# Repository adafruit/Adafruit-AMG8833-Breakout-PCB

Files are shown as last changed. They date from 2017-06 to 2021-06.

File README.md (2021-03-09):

## Adafruit AMG8833 Breakout PCB

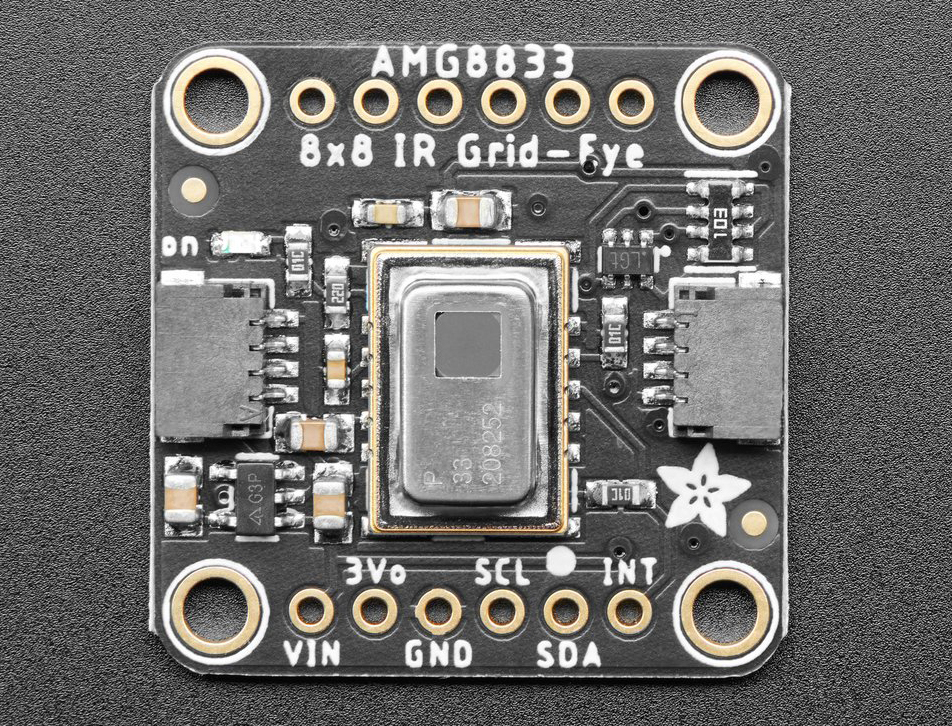
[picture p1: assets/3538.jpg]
<a href="http://www.adafruit.com/products/3538"><br/>
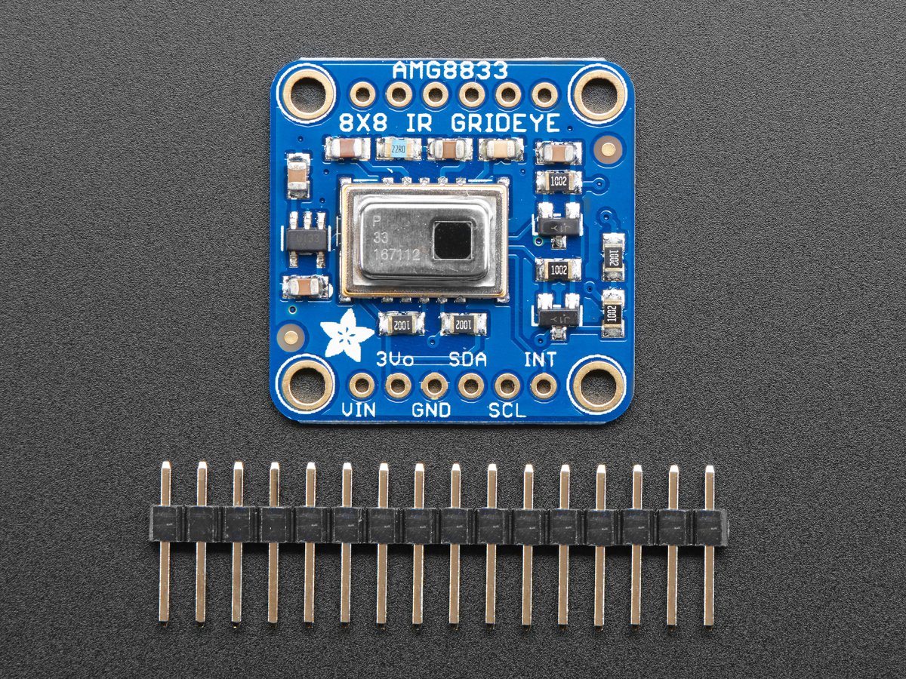
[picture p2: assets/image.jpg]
<a href="http://www.adafruit.com/products/3538"><br/>
Click here to purchase one from the Adafruit shop</a>

PCB files for the Adafruit AMG8833 8x8 IR sensor breakout board. Format is EagleCAD schematic and board layout

For more details, check out the product page at
* https://www.adafruit.com/products/3538

### Description

Add heat-vision to your project and with an Adafruit AMG8833 Grid-EYE Breakout! This sensor from Panasonic is an 8x8 array of IR thermal sensors. When connected to your microcontroller (or raspberry Pi) it will return an array of 64 individual infrared temperature readings over I2C. It's like those fancy thermal cameras, but compact and simple enough for easy integration.

This part will measure temperatures ranging from 0°C to 80°C (32°F to 176°F) with an accuracy of +- 2.5°C (4.5°F). It can detect a human from a distance of up to 7 meters (23) feet. With a maximum frame rate of 10Hz, It's perfect for creating your own human detector or mini thermal camera. We have code for using this breakout on an Arduino or compatible (the sensor communicates over I2C) or on a Raspberry Pi with Python. On the Pi, with a bit of image processing help from the SciPy python library we were able to interpolate the 8x8 grid and get some pretty nice results!

The AMG8833 is the next generation of 8x8 thermal IR sensors from Panasonic, and offers higher performance than it's predecessor the AMG8831. The sensor only supports I2C, and has a configurable interrupt pin that can fire when any individual pixel goes above or below a threshold that you set.

To make it easy to use, we pick & placed it on a breakout board with a 3.3V regulator and level shifting. So you can use it with any 3V or 5V microcontroller or computer.

### License

Adafruit invests time and resources providing this open source design, please support Adafruit and open-source hardware by purchasing products from [Adafruit](https://www.adafruit.com)!

Designed by Limor Fried/Ladyada for Adafruit Industries.

Creative Commons Attribution/Share-Alike, all text above must be included in any redistribution. See license.txt for additional details.

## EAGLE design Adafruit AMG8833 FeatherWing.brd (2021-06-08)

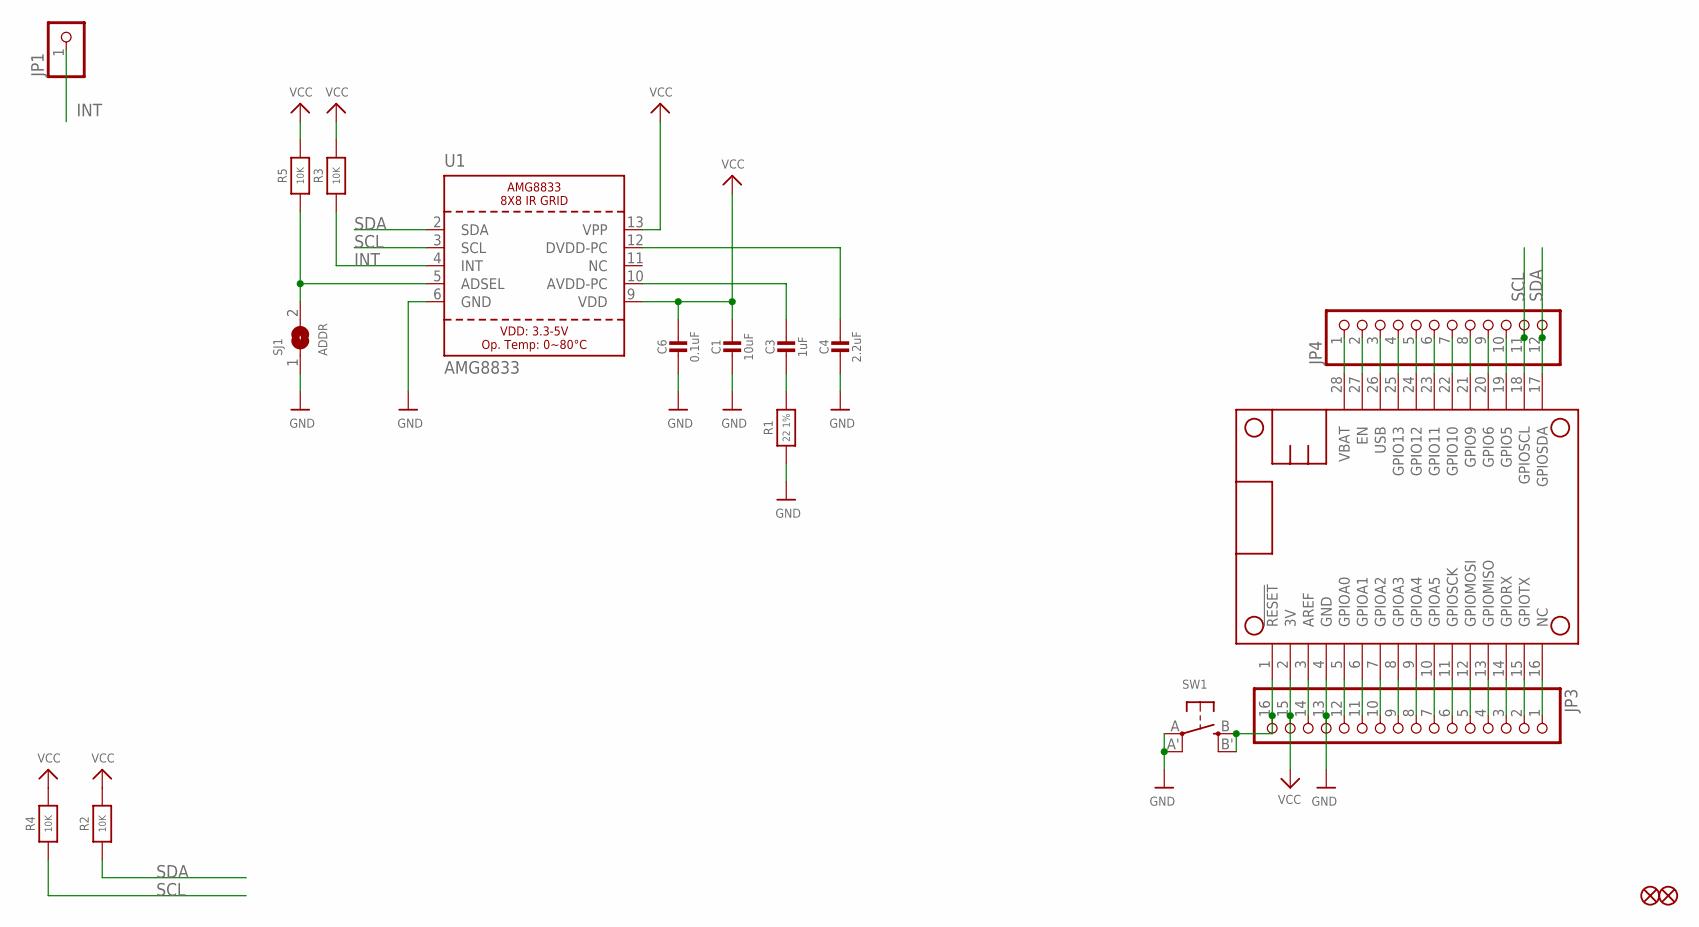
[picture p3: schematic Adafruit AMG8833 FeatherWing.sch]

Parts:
C1: 10uF; 0805-NO
C3: 1uF; 0805-NO
C4: 2.2uF; 0805-NO
C6: 0.1uF; 0805-NO
FID1, FID2: FIDUCIAL""; FIDUCIAL_1MM
JP1: HEADER-1X1ROUND; 1X01_ROUND
JP3: HEADER-1X16ROUND; 1X16_ROUND
JP4: HEADER-1X12; 1X12_ROUND
MS1: FEATHERWING
R1: 22 1%; 0805-NO
R2, R3, R4, R5: 10K; 0805-NO
SJ1: ADDR; SOLDERJUMPER_ARROW_NOPASTE
SW1: SWITCH_TACT_SMT4.6X2.8; BTN_KMR2_4.6X2.8
U1: AMG8833

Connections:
A: JP3.12, MS1.5 (GPIOA0)
AREF: JP3.14, MS1.3 (AREF)
AVDD-PC1: C3.1, U1.10 (AVDD-PC)
B: JP3.11, MS1.6 (GPIOA1)
C: JP3.10, MS1.7 (GPIOA2)
D: JP3.9, MS1.8 (GPIOA3)
DVDD-PC1: C4.1, U1.12 (DVDD-PC)
E: JP3.8, MS1.9 (GPIOA4)
EN: JP4.2, MS1.27 (EN)
F: JP3.7, MS1.10 (GPIOA5)
G: JP3.1, MS1.16 (NC)
GND: C1.2, C4.2, C6.2, JP3.13, MS1.4 (GND), R1.1, SJ1.1, SW1.A, SW1.A' (P1), U1.6 (GND)
H: JP4.10, MS1.19 (GPIO5)
I: JP4.9, MS1.20 (GPIO6)
INT: JP1.1, R3.1, U1.4 (INT)
J: JP4.8, MS1.21 (GPIO9)
K: JP4.7, MS1.22 (GPIO10)
L: JP4.6, MS1.23 (GPIO11)
M: JP4.5, MS1.24 (GPIO12)
MISO: JP3.4, MS1.13 (GPIOMISO)
MOSI: JP3.5, MS1.12 (GPIOMOSI)
N: JP4.4, MS1.25 (GPIO13)
unnamed: R5.1, SJ1.2, U1.5 (ADSEL)
unnamed: C3.2, R1.2
RESET: JP3.16, MS1.1 (!RESET), SW1.B (S), SW1.B' (S1)
RX: JP3.3, MS1.14 (GPIORX)
SCK: JP3.6, MS1.11 (GPIOSCK)
SCL: JP4.11, MS1.18 (GPIOSCL), R4.1, U1.3 (SCL)
SDA: JP4.12, MS1.17 (GPIOSDA), R2.1, U1.2 (SDA)
TX: JP3.2, MS1.15 (GPIOTX)
USB: JP4.3, MS1.26 (USB)
VBAT: JP4.1, MS1.28 (VBAT)
VCC: C1.1, C6.1, JP3.15, MS1.2 (3V), R2.2, R3.2, R4.2, R5.2, U1.9 (VDD), U1.13 (VPP)

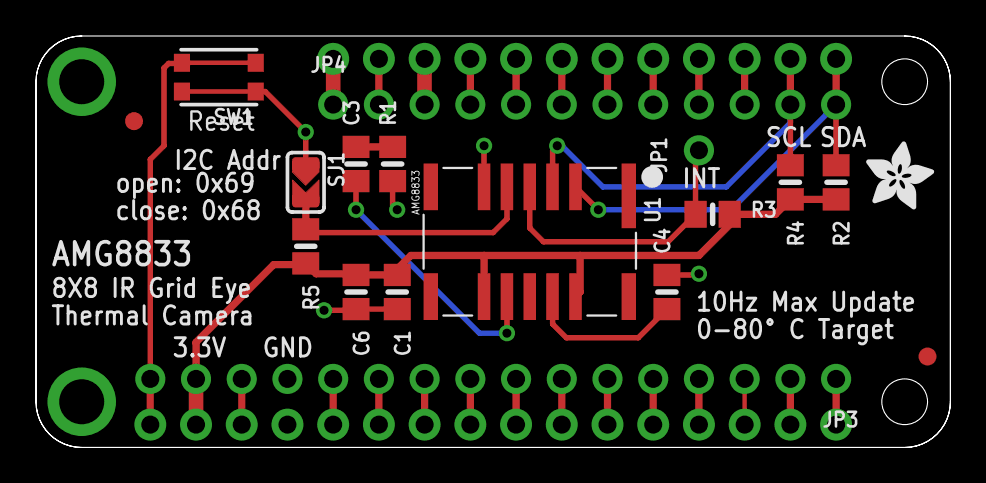
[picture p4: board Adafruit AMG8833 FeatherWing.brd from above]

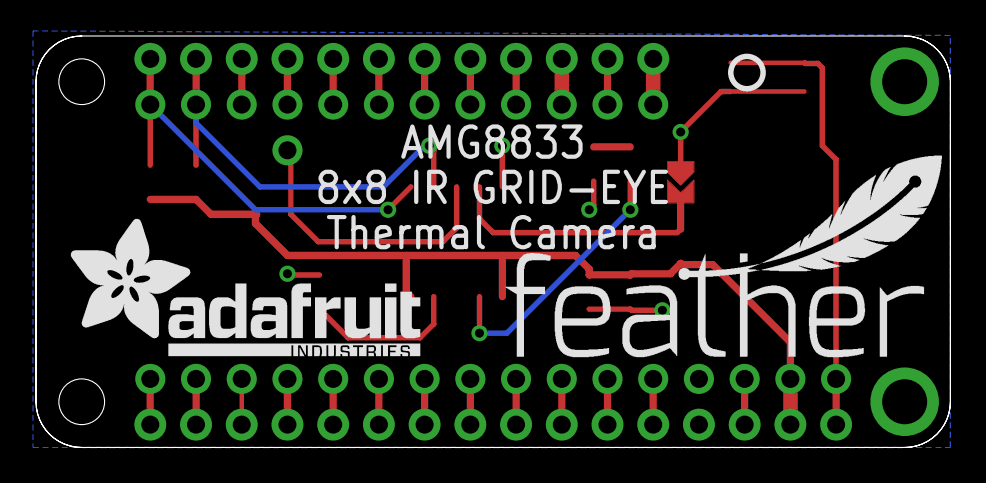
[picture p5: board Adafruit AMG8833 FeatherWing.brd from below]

Board: 2 copper layers, 50.8 x 22.9 mm, 22 parts (3 on the bottom side), 33 nets.

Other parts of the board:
U$2: ADAFRUIT_TEXT_20MM
U$14: ADAFRUIT_3.5MM
U$15: FEATHERLOGO
U$16: PCBFEAT-REV-040

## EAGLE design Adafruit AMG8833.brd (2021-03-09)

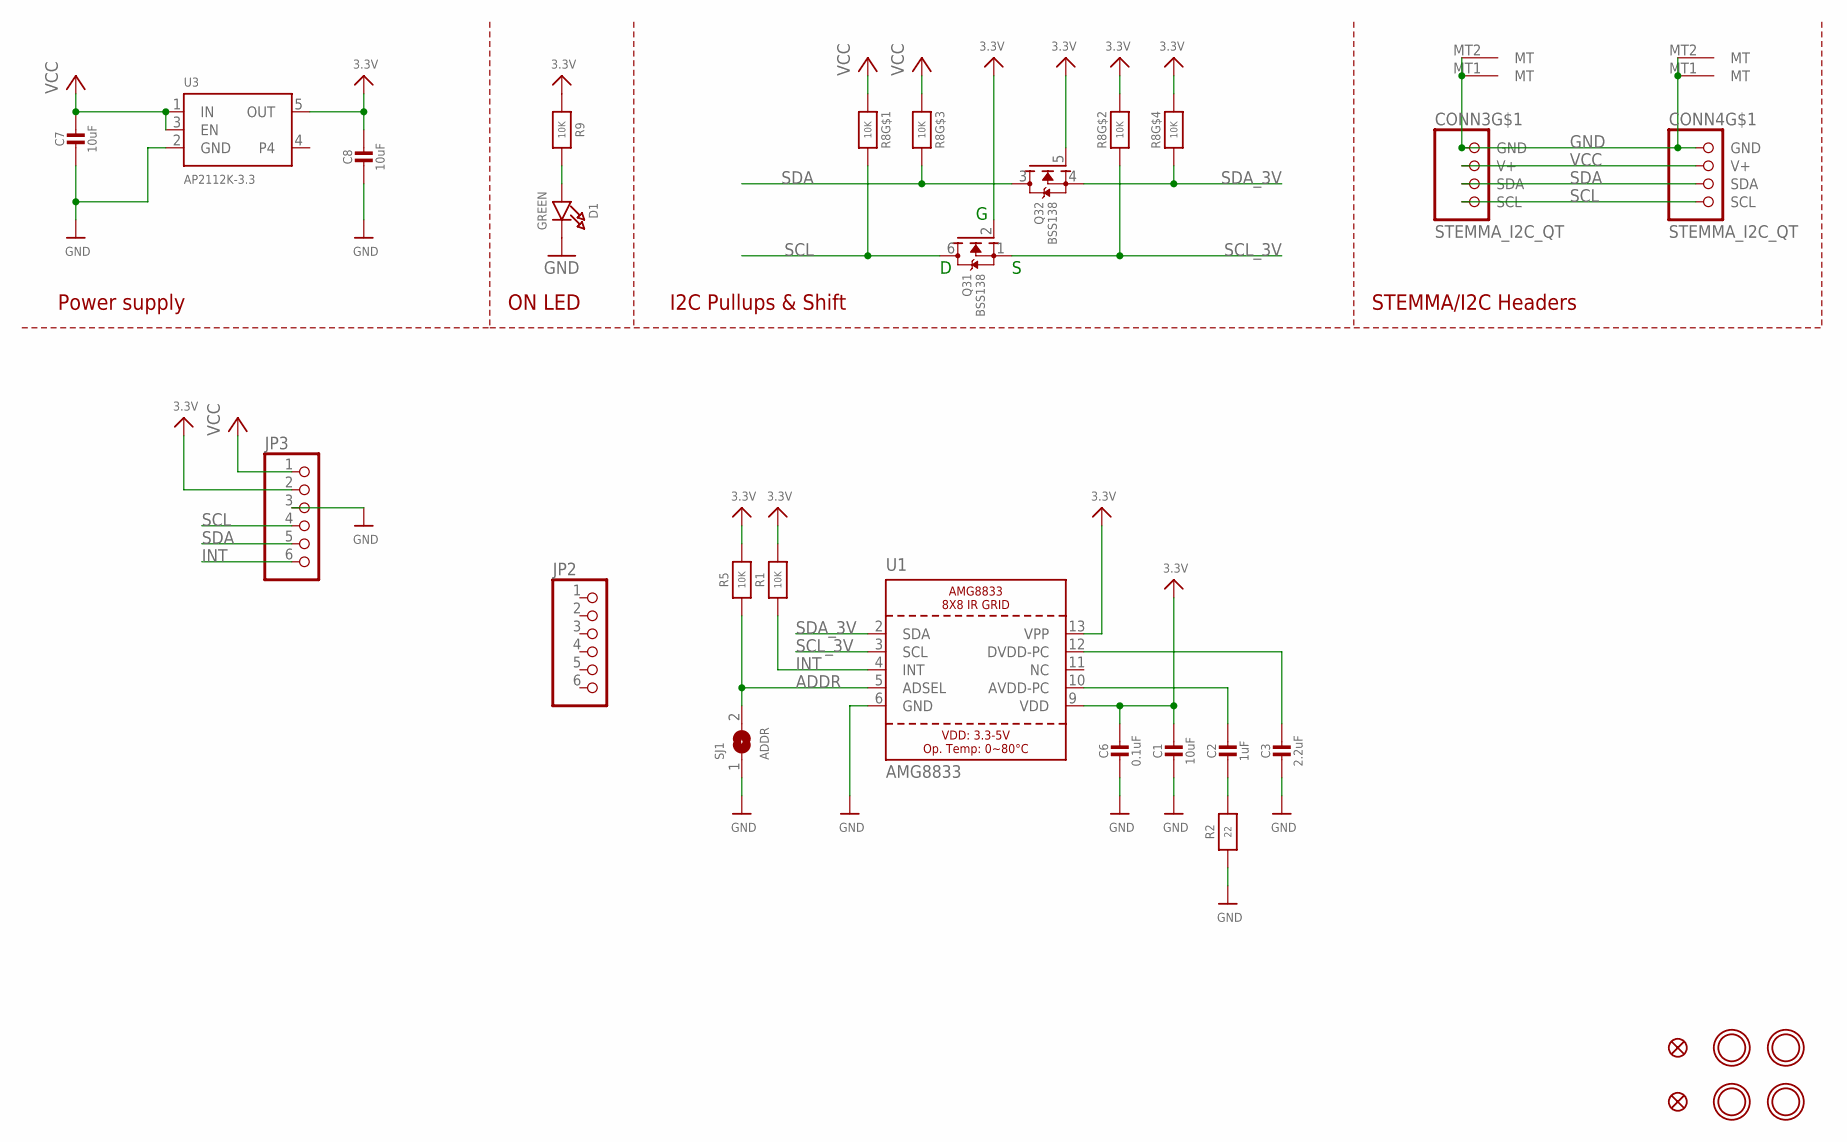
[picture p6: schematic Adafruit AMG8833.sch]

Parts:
C1, C7, C8: 10uF; 0805-NO
C2: 1uF; 0603-NO
C3: 2.2uF; 0805-NO
C6: 0.1uF; 0603-NO
CONN3, CONN4: STEMMA_I2C_QT; JST_SH4
D1: GREEN; CHIPLED_0603_NOOUTLINE
FID1, FID4: FIDUCIAL_1MM
JP2, JP3: HEADER-1X670MIL; 1X06_ROUND_70
Q3: BSS138; SOT363
R1, R5, R9: 10K; 0603-NO
R2: 22; 0603-NO
R8: 10K; RESPACK_4X0603
SJ1: ADDR; SOLDERJUMPER_ARROW_NOPASTE
U1: AMG8833
U3: AP2112K-3.3; SOT23-5
U$40, U$41, U$43, U$44: MOUNTINGHOLE2.5; MOUNTINGHOLE_2.5_PLATED

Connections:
3.3V: C1.1, C6.1, C8.1, JP3.2, Q3.2 (G), Q3.5 (G), R1.2, R5.2, R8.2 (1), R8.4 (1), R9.1, U1.9 (VDD), U1.13 (VPP), U3.5 (OUT)
ADDR: R5.1, SJ1.2, U1.5 (ADSEL)
AVDD-PC: C2.1, U1.10 (AVDD-PC)
DVDD-PC: C3.1, U1.12 (DVDD-PC)
GND: C1.2, C3.2, C6.2, C7.2, C8.2, CONN3.1 (GND), CONN3.MT1 (MT), CONN3.MT2 (MT), CONN4.1 (GND), CONN4.MT1 (MT), CONN4.MT2 (MT), D1.C, JP3.3, R2.1, SJ1.1, U1.6 (GND), U3.2 (GND)
INT: JP3.6, R1.1, U1.4 (INT)
unnamed: D1.A, R9.2
unnamed: C2.2, R2.2
SCL: CONN3.4 (SCL), CONN4.4 (SCL), JP3.4, Q3.6 (D), R8.8 (2)
SCL_3V: Q3.1 (S), R8.7 (2), U1.3 (SCL)
SDA: CONN3.3 (SDA), CONN4.3 (SDA), JP3.5, Q3.3 (D), R8.6 (2)
SDA_3V: Q3.4 (S), R8.5 (2), U1.2 (SDA)
VCC: C7.1, CONN3.2 (V+), CONN4.2 (V+), JP3.1, R8.1, R8.3 (1), U3.1 (IN), U3.3 (EN)

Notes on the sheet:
I2C Pullups & Shift
STEMMA/I2C Headers
ON LED
Power supply

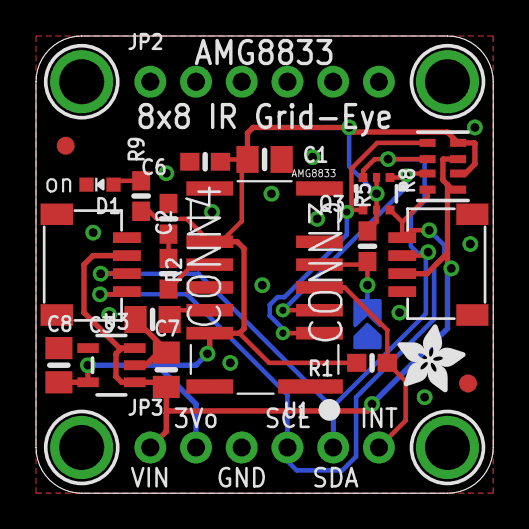
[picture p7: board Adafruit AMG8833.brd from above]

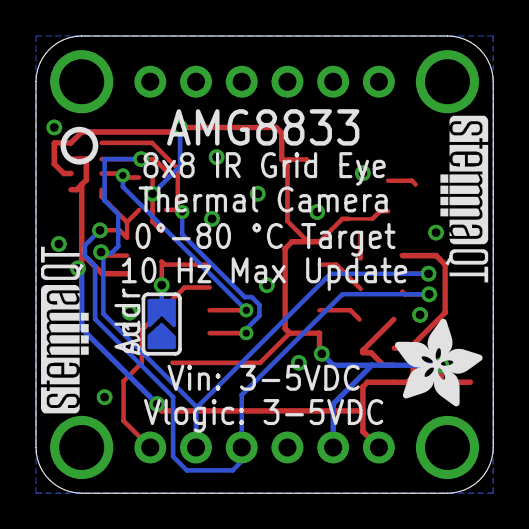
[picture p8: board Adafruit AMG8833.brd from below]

Board: 2 copper layers, 25.4 x 25.4 mm, 31 parts (5 on the bottom side), 13 nets.

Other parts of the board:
U$28: ADAFRUIT_5MM
U$46: ADAFRUIT_3.5MM
U$47: PCBFEAT-REV-040
U$48, U$49: STEMMAQT

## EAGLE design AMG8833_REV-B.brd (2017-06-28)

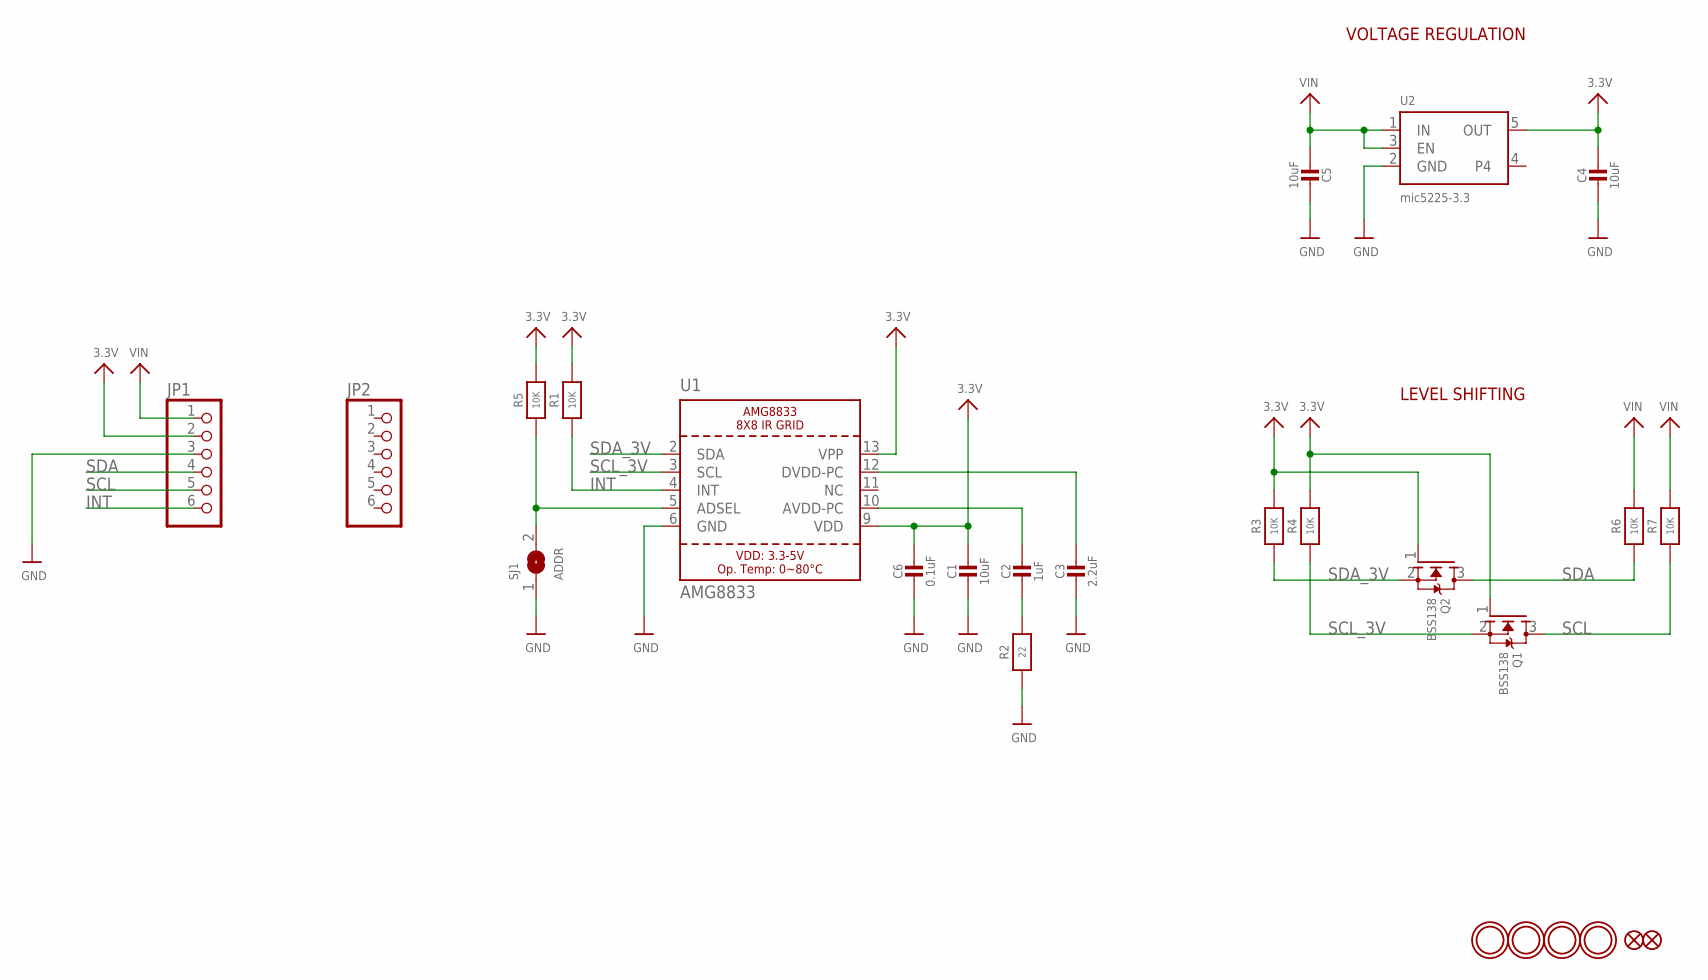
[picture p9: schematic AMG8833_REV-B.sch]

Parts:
C1, C4, C5: 10uF; 0805-NO
C2: 1uF; 0805-NO
C3: 2.2uF; 0805-NO
C6: 0.1uF; 0805-NO
FID2, FID3: FIDUCIAL_1MM
JP1, JP2: HEADER-1X670MIL; 1X06_ROUND_70
Q1, Q2: BSS138; SOT23-WIDE
R1, R3, R4, R5: 10K; 0805-NO
R2: 22; 0805-NO
R6, R7: 10K; 0805_10MGAP
SJ1: ADDR; SOLDERJUMPER_ARROW_NOPASTE
U1: AMG8833
U2: mic5225-3.3; SOT23-5
U$16, U$17, U$18, U$19: MOUNTINGHOLE2.5; MOUNTINGHOLE_2.5_PLATED

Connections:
3.3V: C1.1, C4.1, C6.1, JP1.2, Q1.1 (G), Q2.1 (G), R1.2, R3.2, R4.2, R5.2, U1.9 (VDD), U1.13 (VPP), U2.5 (OUT)
AVDD-PC: C2.1, U1.10 (AVDD-PC)
DVDD-PC: C3.1, U1.12 (DVDD-PC)
GND: C1.2, C3.2, C4.2, C5.1, C6.2, JP1.3, R2.1, SJ1.1, U1.6 (GND), U2.2 (GND)
INT: JP1.6, R1.1, U1.4 (INT)
unnamed: R5.1, SJ1.2, U1.5 (ADSEL)
unnamed: C2.2, R2.2
SCL: JP1.5, Q1.3 (D), R7.1
SCL_3V: Q1.2 (S), R4.1, U1.3 (SCL)
SDA: JP1.4, Q2.3 (D), R6.1
SDA_3V: Q2.2 (S), R3.1, U1.2 (SDA)
VIN: C5.2, JP1.1, R6.2, R7.2, U2.1 (IN), U2.3 (EN)

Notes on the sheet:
VOLTAGE REGULATION
LEVEL SHIFTING

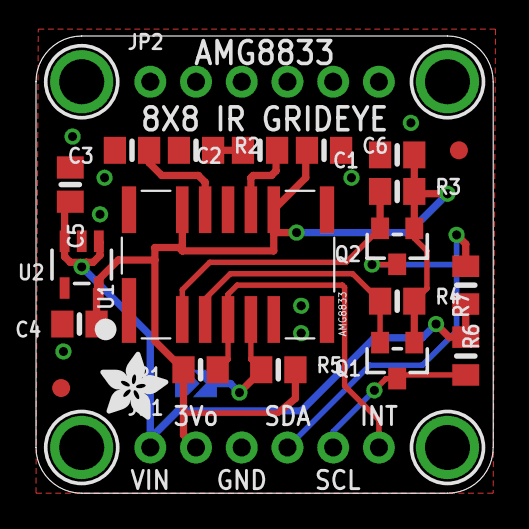
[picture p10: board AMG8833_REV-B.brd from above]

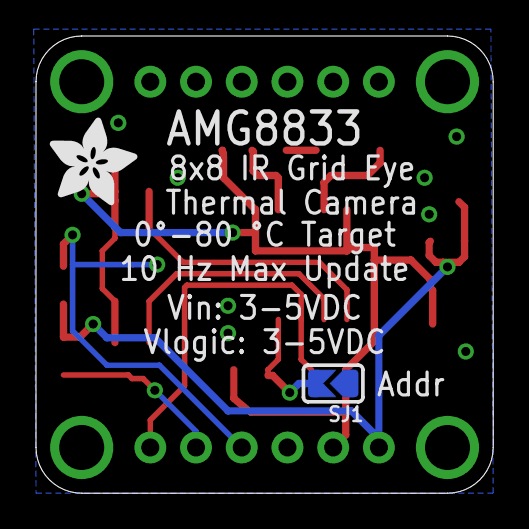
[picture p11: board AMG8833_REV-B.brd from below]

Board: 2 copper layers, 25.4 x 25.4 mm, 28 parts (2 on the bottom side), 12 nets.

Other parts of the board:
U$21: ADAFRUIT_3.5MM
U$28: ADAFRUIT_5MM

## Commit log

2021-03-09 Add board files.
    [Adafruit AMG8833.brd, Adafruit AMG8833.sch]
2021-06-08 Add FeatherWing board files.
    [Adafruit AMG8833 FeatherWing.brd, Adafruit AMG8833 FeatherWing.sch]

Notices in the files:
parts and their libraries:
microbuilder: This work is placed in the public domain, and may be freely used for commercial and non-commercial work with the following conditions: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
